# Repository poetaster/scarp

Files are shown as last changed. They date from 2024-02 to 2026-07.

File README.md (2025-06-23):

# scarp
The scarp project, named like it's brethren, rampart and keep (aka. moat) is an experimental, open hardware design. 

PCB

It can include a 4pin I2C display. Or a three pin I2S DAC. All the pins on the pico are exposed and you can add headers to use them.

The board uses all GPIO. 8 buttons, 8 leds, 2 pots and an encoder.

The firmware directory includes a number of types of firmware. You'll be able to do work with the bare pico sdk, circuitpython, or arduino. 

# firmwares
Include examples for
 *  NEW 05.2025 a port of Mutable instruments braids to scarp. Requires the STMLIB and BRAIDS libraries from https://github.com/poetaster/arduinoMI/
 *  Mozzi library based c++. 
 * Arduino PWM pikobeats variant. 
 * pikocore  The scarp branch here: https://github.com/poetaster/pikocore/tree/scarp allows you to play the pikocore firmware, with some tweaks to adapt to this hardware layout.
 * circuitpython - There is also an elaborate circuitpython audio example based on todbots https://github.com/todbot/picostepseq but including audio output ;)

I sell my tonetoys synths at https://poetaster.org or on etsy at https://tonetoys.etsy.com, or Tindie :)


 
I've had a bunch of fun with:

A Drum sequencer for the Pikocore, https://github.com/poetaster/PikoBeats, derived from https://github.com/rheslip/PikoBeats .

This project was inspired by Teenage Engineering, pikocore designed by Zack Scholl https://infinitedigits.co/wares/pikocore/, the todbot circuit python audio stuff and his layouts for a simple sequencer. Please visit Zack's site to buy a Pikocore, a kit, or a PCB - its a really fun little sample glitcher.

THIS BOARD is in production and the first version, with only pwm output works really well!.

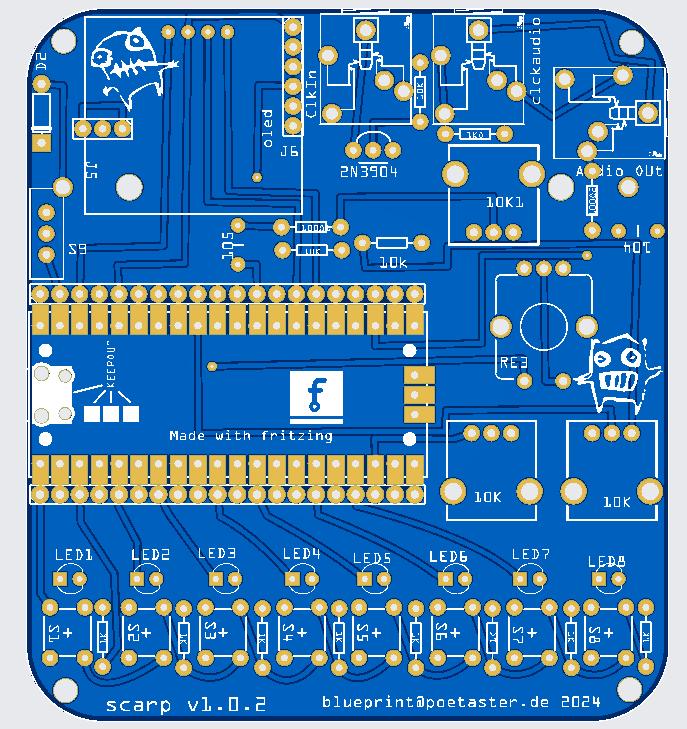
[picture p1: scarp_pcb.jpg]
PCB


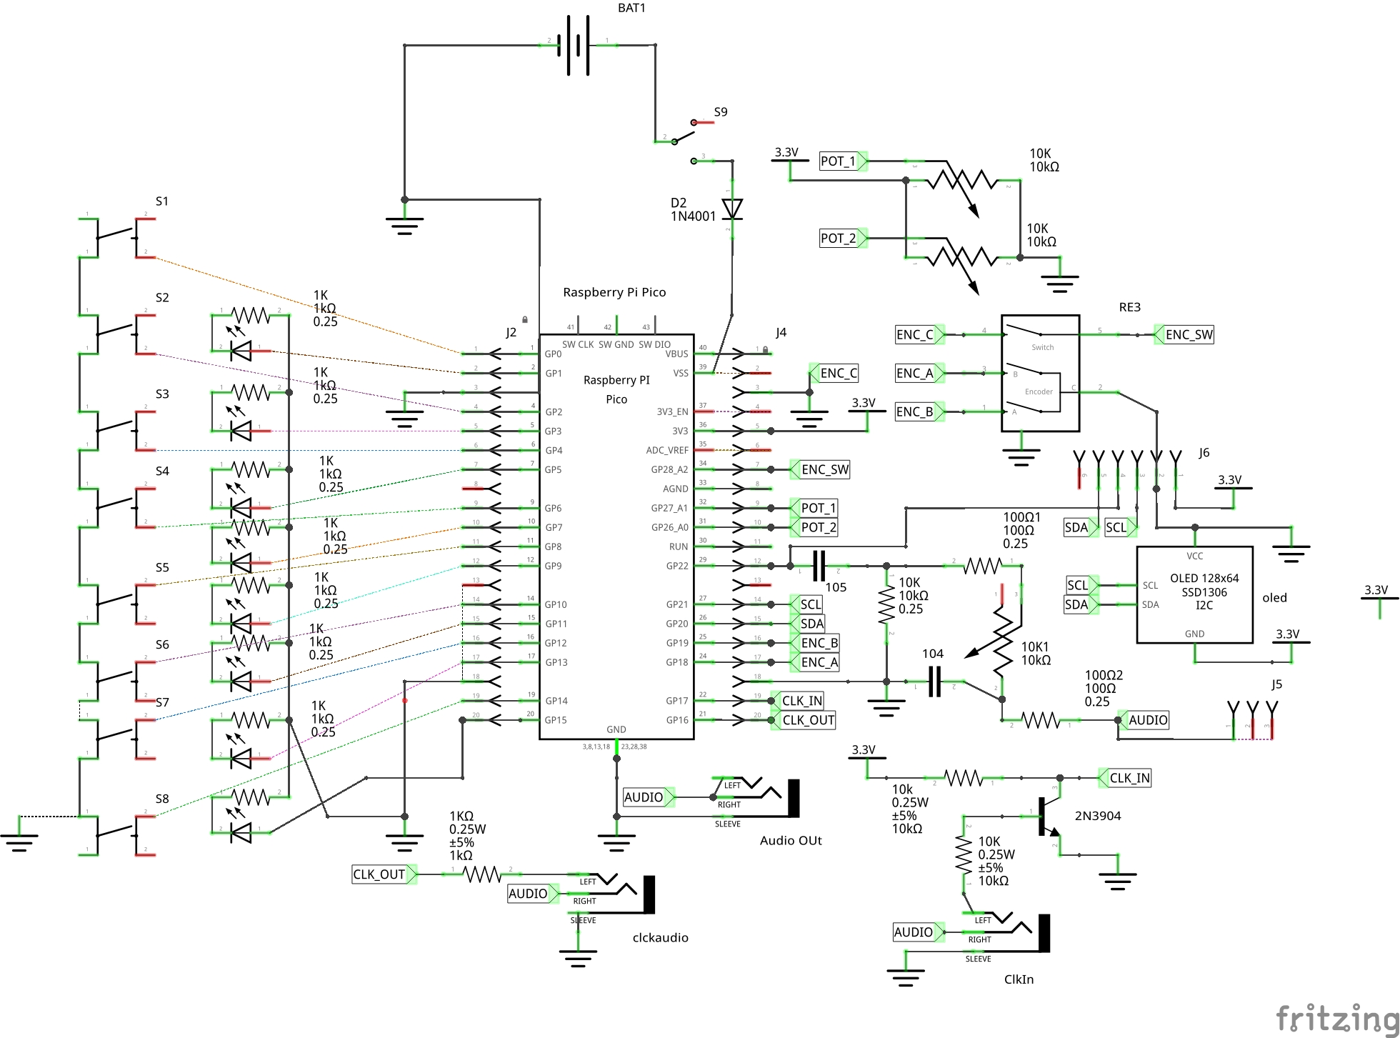
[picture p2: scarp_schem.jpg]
Schematic


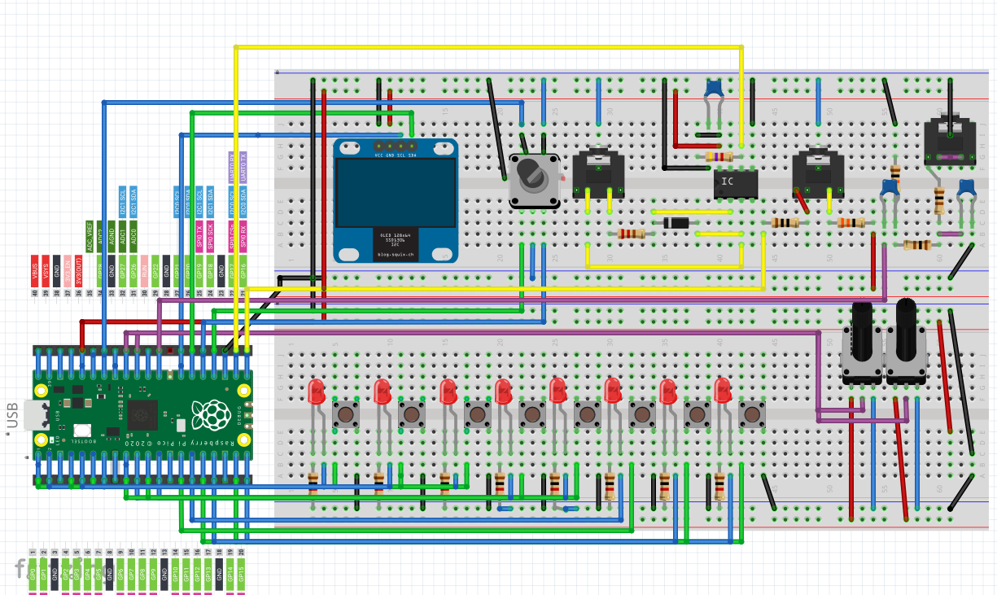
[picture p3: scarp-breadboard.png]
Breadboard


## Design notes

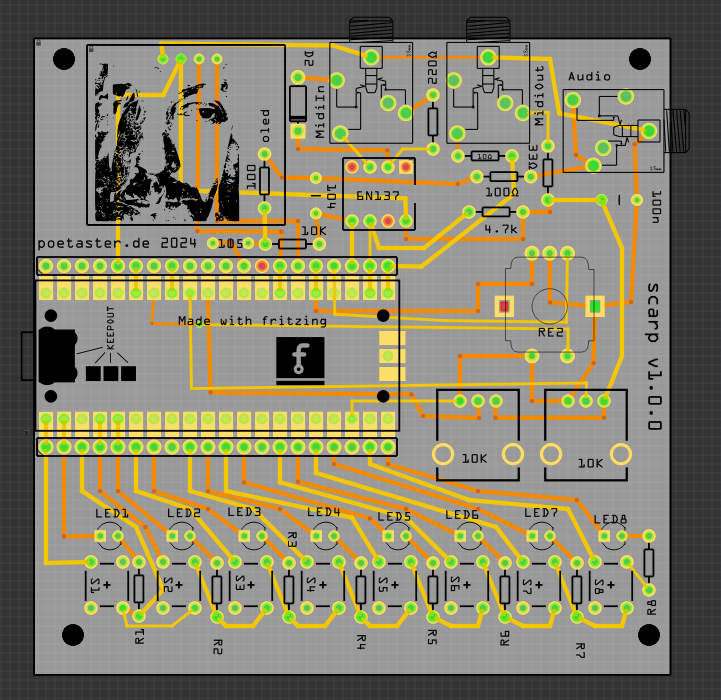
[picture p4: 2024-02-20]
scarp-pcb.png

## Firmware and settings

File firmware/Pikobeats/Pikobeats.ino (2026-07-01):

/* Copyright 2023 Rich Heslip, 2024-2025 Mark Washeim

  Author: Rich Heslip (ORIGINAL AUTHOR)
  Author: Mark Washeim <blueprint@poetaster.de>

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
  See http://creativecommons.org/licenses/MIT/ for more information.

  -----------------------------------------------------------------------------


  // sample player inspired by Jan Ostman's ESP8266 drum machine http://janostman.wordpress.com

  samples for beatbox from:
  giddster ( https://freesound.org/people/giddster/ )
  AlienXXX ( https://freesound.org/people/AlienXXX/

  The euclid code originates at:
  https://github.com/bastl-instruments/one-chip-modules/blob/master/EUCLID/EUCLID.ino

*/

#include <Arduino.h>
#include "stdio.h"
#include "pico/stdlib.h"
#include "hardware/gpio.h"
#include "hardware/sync.h"
#include "hardware/structs/ioqspi.h"
#include "hardware/structs/sio.h"

#include <EEPROM.h>
#include <PWMAudio.h>
#include <Wire.h>
#include <RotaryEncoder.h>

#include "io.h"
#include "euclid.h"

#include <math.h>     // tanhf for the output soft-clip
//#include "filter.h"

bool debug = false;
uint8_t device_initialized = 0;

// display setup works with adafruit SSD1306 or SH1106G
const int dw = 128;
const int dh = 64;
const int oled_sda_pin = 20;
const int oled_scl_pin = 21;
const int oled_i2c_addr = 0x3C;
#define OLED_RESET     -1 // Reset pin # (or -1 if sharing Arduino reset pin)
#define SCREEN_ADDRESS 0x3C ///< See datasheet for Address; 0x3D for 128x64, 0x3C for 128x32

//#include <Adafruit_SSD1306.h>
//Adafruit_SSD1306 display(dw, dh, &Wire, OLED_RESET);
//#define SCREEN_ADDRESS 0x3D ///< See datasheet for Address; 0x3D for 128x64, 0x3C for 128x32

#include <Adafruit_SH110X.h>
Adafruit_SH1106G display = Adafruit_SH1106G(128, 64, &Wire);
#define WHITE SH110X_WHITE
#include "font.h"
#include "helvnCB6pt7b.h"
#define myfont Org_01 //helvnCB6pt7b // Org_01 looks better but is small.
#define bigfont helvnCB6pt7b

#define DISPLAY_TIME 2000 // time in ms to display numbers on LEDS
int32_t display_timer;


// rotate trigger pattern
uint16_t rightRotate(int shift, uint16_t value, uint8_t pattern_length) {
  uint16_t mask = ((1 << pattern_length) - 1);
  value &= mask;
  return ((value >> shift) | (value << (pattern_length - shift))) & mask;
}

// clock timer we use for clk input and encoder input bpm setting
#define TIMER_INTERRUPT_DEBUG         0
#define _TIMERINTERRUPT_LOGLEVEL_     4
#include "RPi_Pico_TimerInterrupt.h"
#define TIMER0_INTERVAL_MS       1
#define DEBOUNCING_INTERVAL_MS   4// 80
#define LOCAL_DEBUG              1

// Init RPI_PICO_Timer, can use any from 0-15 pseudo-hardware timers
RPI_PICO_Timer ITimer0(0);

volatile unsigned long rotationTime = 0;
volatile float RPM       = 0.00;
float avgRPM    = 0.00;
volatile int debounceCounter;

int current_track = 0; // track we are working on

// input clk tracking
volatile int clk_state_last; // track the CLOCKIN pin state.
int clk_state = 0;
int clk_hits = 0;
uint32_t clk_sync_ms = 0;
bool sync = false; // used to detect if we have input sync
volatile int clk_display;
uint32_t clk_sync_last;

bool TimerHandler0(struct repeating_timer *t)
{
  (void) t;
  
  bool clockstate = digitalRead(CLOCKIN) ;
  
  if ( clockstate && clk_state_last != clockstate && (debounceCounter >= DEBOUNCING_INTERVAL_MS ) ) {
    //min time between pulses has passed
    // calculate bpm
    RPM = (float) ( 60000.0f / ( rotationTime * TIMER0_INTERVAL_MS ) / 2.0f );
    clk_display = RPM;
    // these are for the sequencer
    sync = true;
    rotationTime = 0;
    debounceCounter = 0;
  } else {
    debounceCounter++;
  }

  if (rotationTime >= 1000) {
    // If idle, set RPM to 0, don't increase rotationTime
    sync = false ;// flag for seq.h
    RPM = 0;
    rotationTime = 0;
  } else {
    rotationTime++;
  }

  clk_state_last = clockstate;
  return true;

}

// begin hardware definitions
const int key_pins[] = { 0, 2, 4, 6, 8, 10, 12, 14 };
const int led_pins[] = { 1, 3, 5, 7, 9, 11, 13, 15 };

// on the long ec11 these are swapped A 19, B 18
const int encoderA_pin = 18;
const int encoderB_pin = 19;
const int encoderSW_pin = 28;

// Encoder direction. 1 = normal, -1 = inverted. The CI builds both variants by
// passing -DCHAMBORD_ENC_DIR=... ; to change it locally edit the default below.
#ifndef ENC_DIR
#define ENC_DIR 1
#endif
const int ENCODER_DIR = ENC_DIR;


// encoder
RotaryEncoder encoder(encoderB_pin, encoderA_pin, RotaryEncoder::LatchMode::FOUR3);

void checkEncoderPosition() {
  encoder.tick();   // call tick() to check the state.
}

// variables for UI state management
int encoder_pos_last = 0;
int encoder_delta = 0;
uint32_t encoder_push_millis;
uint32_t step_push_millis;
uint8_t selected_preset = 0;
uint8_t selected_slot   = 0; // saving to

// the display is offset + 1
uint8_t display_preset = 0;
uint8_t display_slot = 0;

uint8_t loadSave = 0;
bool loading = false;

// currently not used
int step_push = -1;
bool step_edited = false;
char seq_info[11];  // 10 chars + nul FIXME

bool encoder_held = false;

// pots & buttons settings and functions
#include "pots.h"


enum {
  MODE_PLAY = 0,
  MODE_CONFIG,
  MODE_COUNT   // how many modes we got
};

int display_mode = MODE_PLAY;
uint8_t display_repeats = 0;
uint8_t display_fills = 0;
uint8_t display_rand = 0;
uint8_t display_samp = 0;
uint8_t display_vol = 175;
uint8_t display_pitch = 128;
String display_pat;

int modulation_timer = 0;
int rotation_timer = 0;
uint8_t last_mod_chan = 0;
uint8_t last_rot_chan = 0;

// from pikocore filter NOT used currently
/*
  uint8_t filter_fc = LPF_MAX + 10;
  uint8_t hpf_fc = 0;
  uint8_t filter_q = 0;
*/

//#define MONITOR_CPU  // define to monitor Core 2 CPU usage on pin CPU_USE

// setup audio hardware
#define SAMPLERATE 44100 // VCC-GND 16mb flash boards won't overclock fast enough for 44khz ?
PWMAudio DAC(PWMOUT);  // 16 bit PWM audio

/* we have 8 voices that can play any sample when triggered
  this structure holds the settings for each voice
  each voice has 4 samples assigned to it for a total of 32
  we use a header per sample set
  we can have an arbitrary number of samples but you will run out of memory at some point

  sound sample files are 22khz 16 bit signed PCM format - see the sample include files for examples
  you can change the sample rate to whatever you want but most testing was done at 22khz. 44khz probably works but not much testing was done
  use the wave2header22khz.exe utility to automagically batch convert all the .wav files in a directory into the required header files
  put your 22khz or 44khz PCM wav files in a sample subdirectory with a copy of the utility, run the utility and it will generate all the required header files
  wave2header creates a header file containing the signed PCM values for each sample - note that it may change the name of the file if required to make it "c friendly"
  wave2header also creates sampledefs.h which is an array of structures containing information about each sample file
  the samples are arranged in alphabetical order to facilitate grouping samples by name - you can manually edit this file to change the order of the samples as needed
  sampledefs.h contains other information not used by this program e.g. the name of the sample file - I wrote it for another project
   wave2header also creates "samples.h" which #includes all the generated header files
*/

#define KIT_HIPHOP

#if   defined(KIT_80S)
  #include "80s.h"
#elif defined(KIT_ANGULARJ)
  #include "angularj.h"
#elif defined(KIT_MIX)
  #include "mixp.h"
#elif defined(KIT_TEKKE)
  #include "tekke.h"
#elif defined(KIT_HIPHOP)
  #include "hiphop.h"
#else
  #include "trippy.h"
#endif

// the beatboxes need to be redone 02.12.2025
//#include "beatbox.h"
//#include "bbox.h"

#define NUM_SAMPLES (sizeof(sample)/sizeof(sample_t))


// include here to avoid forward references - I'm lazy :)
#include "seq.h"
#include "eeprom.h"

bool saveStatus = false;
#include "display.h"

// ---------------------------------------------------------------------------
// Audio mixing: precomputed per-voice gain + attack ramp (anti-click)
// Derived from wgd chambord
// ---------------------------------------------------------------------------

#define RAMP_LEN 48                 // ~1.1ms attack at 44.1kHz to kill retrigger clicks
int32_t  voice_gain[NTRACKS];       // Q15 gain (level/1000) precomputed so the mix loop has no divide
uint16_t voice_ramp[NTRACKS];       // attack ramp counter per track, counts up to RAMP_LEN

// set a track level (0-1000) and recompute its Q15 mix gain
inline void setLevel(int track, int level) {
  if (level < 0) level = 0;
  if (level > 1000) level = 1000;
  voice[track].level = level;
  voice_gain[track] = ((int32_t)level * 32768) / 1000;
}

bool starting = false;

// main core setup
void setup() {
  // set clock speed as in picokore
  //set_sys_clock_khz(264000, true); don't do this :)

  Serial.begin(115200);

  if (debug) {
    Serial.print(F("\nStarting RPM_Measure on ")); Serial.println(BOARD_NAME);
    Serial.println(RPI_PICO_TIMER_INTERRUPT_VERSION);
    Serial.print(F("CPU Frequency = ")); Serial.print(F_CPU / 1000000); Serial.println(F(" MHz"));
  }
  // Interval in microsecs
  if (ITimer0.attachInterruptInterval(TIMER0_INTERVAL_MS * 1000, TimerHandler0))
  {
    Serial.print(F("Starting  ITimer0 OK, millis() = ")); Serial.println(millis());
  }  else {
    Serial.println(F("Can't set ITimer0. Select another freq. or timer"));
  }
  //Serial.flush();

  // Additions
  // ENCODER
  pinMode(encoderA_pin, INPUT_PULLUP);
  pinMode(encoderB_pin, INPUT_PULLUP);
  attachInterrupt(digitalPinToInterrupt(encoderA_pin), checkEncoderPosition, CHANGE);
  attachInterrupt(digitalPinToInterrupt(encoderB_pin), checkEncoderPosition, CHANGE);

  // DISPLAY need to tell Wire which pins for i2c
  Wire.setSDA(oled_sda_pin);
  Wire.setSCL(oled_scl_pin);
  Wire.begin();

  // SSD1306 --
  //if (!display.begin(SSD1306_SWITCHCAPVCC, oled_i2c_addr)) {
  if (!display.begin( oled_i2c_addr)) {
    Serial.println(F("SSD1306 allocation failed"));
    for (;;) ;  // Don't proceed, loop forever
  }

  displaySplash();
  //displayConfig();

  // end Additions

#ifdef MONITOR_CPU
  pinMode(CPU_USE, OUTPUT); // for monitoring CPU usage
#endif

  pinMode(BUTTON0, INPUT_PULLUP);
  pinMode(BUTTON1, INPUT_PULLUP);
  pinMode(BUTTON2, INPUT_PULLUP);
  pinMode(BUTTON3, INPUT_PULLUP);
  pinMode(BUTTON4, INPUT_PULLUP);
  pinMode(BUTTON5, INPUT_PULLUP);
  pinMode(BUTTON6, INPUT_PULLUP);
  pinMode(BUTTON7, INPUT_PULLUP);
  pinMode(SHIFTBUTTON, INPUT_PULLUP);

  pinMode(AIN0, INPUT);
  pinMode(AIN1, INPUT);

  pinMode(LED0, OUTPUT);
  pinMode(LED1, OUTPUT);
  pinMode(LED2, OUTPUT);
  pinMode(LED3, OUTPUT);
  pinMode(LED4, OUTPUT);
  pinMode(LED5, OUTPUT);
  pinMode(LED6, OUTPUT);
  pinMode(LED7, OUTPUT);

  pinMode(CLOCKOUT, OUTPUT);
  pinMode(CLOCKIN, INPUT_PULLUP);

  pinMode(23, OUTPUT); // thi is to switch to PWM for power to avoid ripple noise
  digitalWrite(23, HIGH);

  display_value(NUM_SAMPLES); // show number of samples on the display

  // init per-voice mix gains and ramps, then restore saved settings from flash
  for (int t = 0; t < NTRACKS; ++t) {
    setLevel(t, voice[t].level);
    voice_ramp[t] = RAMP_LEN;   // not ramping until first trigger
  }

  // try to retrieve saved preset if not, init slots
  EEPROM.begin(2048); // the 8 slots we save now are only 384 bytes, but it'll probably grow
  delay(50);

  starting = true;



  // we read the first byte to try to get a preset, stored 0-7
  if (starting) {
    loading = true;
    loadInit();
    if (device_initialized == 7 ) {

      loadLastPreset(); // sets selected_preset from base eeprom save point
      loadMemorySlots();
      if (selected_preset > -1 && selected_preset < 8) {

        loadFromMemorySlot(selected_preset);

      } else {
        loadFromMemorySlot(0);
      }

    } else {
      // first use of device, so prep it.
      initializeEEPROM(); // first run, get settings into all 8 slots
      currentConfig = defaultSlots[0]; // current config is default 0
      bpm = currentConfig.tempo;
      internalClock = currentConfig.internalClock;
      selected_preset = 0;
      saveCurrentPreset(selected_preset); // save to eeprom

      updateRythm(); // update the sequencers

      writeInit(); // set flag so we don't repeat
    }

    starting = false;
    loading = false;
  }

  // init per-voice mix gains and ramps, then restore saved settings from flash
  for (int t = 0; t < NTRACKS; ++t) {
    setLevel(t, voice[t].level);
    voice_ramp[t] = RAMP_LEN;   // not ramping until first trigger
  }


  // now start the dac
  // set up Pico PWM audio output
  DAC.setBuffers(4, 128); // DMA buffers
  DAC.begin(SAMPLERATE);
  delay(100);
  modulation_timer = millis();
  rotation_timer = millis();
}



// main core handles UI

void loop() {


  bool anybuttonpressed;
  // timer
  uint32_t now = millis();



  // UI handlers
  // first encoder
  encoder.tick();
  int encoder_pos = encoder.getPosition();
  if ( (encoder_pos != encoder_pos_last )) {
    encoder_delta = (encoder_pos - encoder_pos_last) * ENCODER_DIR;
  }


  // set play mode 0 play 1 edit patterns, 3 FX?
  if (encoder_push_millis > 0 ) {

    // first mode change on encoder button push, short
    if ((now - encoder_push_millis) < 100 && ! encoder_delta ) {
      if ( !encoder_held ) {
        encoder_held = true;
        display_mode = display_mode + 1;
        if ( display_mode > 3) { // switched back to play mode
          display_mode = 0;
          //configure_sequencer();
        }
      }
    } else if ( (now - encoder_push_millis) > 100 && ! encoder_delta && display_mode == 3 ) {
      // or change  between load and save preset
      //loadSave = !loadSave ; // toggle between load and save
    }

    if (step_push_millis > 0) { // we're pushing a step key too
      if (encoder_push_millis < step_push_millis) {  // and encoder was pushed first
        //strcpy(seq_info, "saveseq");
      }
    }
  }

  anybuttonpressed = false;

  for (int i = 0; i <= 8; ++i) { // scan all the buttons
    if (button[i]) {

      saveStatus = false; // for display when saving
      anybuttonpressed = true;

      // a track button is pressed
      current_track = i; // keypress selects track we are working on

      // use encoder delta with selected button to set sample for track
      if ( (encoder_pos != encoder_pos_last ) && ! button[8] && display_mode == 0) {
        voice[i].isPlaying = false;
        // here we rotate at offset since we're now arranging sample sets in groups of 4
        // currently only really works with 'mix.h'
        int result ;
        if (encoder_delta > 0) {
          result = voice[current_track].sample + 8 ;
        } else {
          result = voice[current_track].sample - 8 ;
        }
        if (result >= 0 && result <= NUM_SAMPLES - 1) {
          voice[current_track].sample = result;
          voice_ramp[current_track] = 0; // re-attack to soften the swap if it's ringing
          currentConfig.sample[i] = result; // save config 0 - 31

        }
      }

      // use encoder button with selected button to set the offset
      if ( (encoder_pos != encoder_pos_last ) && display_mode == 1 ) {
        int repeats = seq[current_track].repeats;
        repeats = constrain( (repeats + encoder_delta), 0, 5);
        seq[i].repeats = repeats;

        // repeats are actually now OFFSET. the repeats mechanism with rotate
        // was disturbing

        display_repeats = repeats;
        seq[i].trigger->rotate(repeats);
        currentConfig.offset[i] = repeats;

        // if offset is 0, reset
        if (repeats == 0 && currentConfig.randy[i] == 0) {
          seq[i].trigger->generateSequence(seq[i].fills, 16);
        } else if (repeats == 0 && currentConfig.randy[i] == 1) {
          seq[i].trigger->generateRandomSequence(seq[i].fills, 16);
        }

      }
      // either restrieve or save preset
      if ( display_mode == 3 &&  ! button[8] ) {
        if (loadSave == 0 && ! loading ) {
          loading = true;
          currentConfig.tempo = bpm;
          updateMemorySlot(selected_preset); // update the memory slot before switching
          selected_preset = current_track;
          saveToEEPROM(current_track);
          saveStatus = true;
          loading = false;
          //saveStatus = false;


        } else if (loadSave == 1 && ! loading && selected_preset != current_track) {
          loading = true; // make sure audio is off
          currentConfig.tempo = bpm;
          updateMemorySlot(selected_preset); // update the memory slot before switching
          selected_preset = current_track; // set selected preset
          loadFromMemorySlot(current_track); // load it from memory
          loading = false;
        }

      }

      // change pitch on pot 0
      if (!potlock[0] && ( display_mode == 0 || display_mode == 2) ) { // change sample if pot has moved enough
        uint16_t pitch = (uint16_t)(map(potvalue[0], POT_MIN, POT_MAX, 2048, 8160));
        // divisible by 2 and it won't click
        if (pitch % 2 == 0) {
          voice[current_track].sampleincrement = pitch;  // change sample pitch if pot has moved enough
          display_pitch = constrain( (pitch >> 5), 1, 255) ; // show 8 bits, which we also store
          currentConfig.pitch[i] = display_pitch; // update config for this channel
        }
      }

      // change sample volume level if pot has moved enough
      if (!potlock[1] && display_mode == 0) {
        int16_t level = (int16_t)(map(potvalue[1], POT_MIN, POT_MAX, 0, 1023));
        voice[current_track].level = level;
        setLevel(current_track, voice[current_track].level);
        display_vol = constrain( ( level >> 2 ), 1, 255); // show 8 bits which we store
        currentConfig.volume[i] = display_vol;
      }
      if (!potlock[0] && display_mode == 1 ) {
        // set track euclidean triggers, random, if either pot has moved enough
        //filter_fc = potvalue[0] * (LPF_MAX + 10) / 4096;
        seq[i].fills = map(potvalue[0], POT_MIN, POT_MAX, 0, 16);
        seq[i].trigger->generateRandomSequence(seq[i].fills, 16);
        currentConfig.randy[i] = 1;
        currentConfig.fills[i] = seq[i].fills;

      }

      // set track euclidean triggers if either pot has moved enough
      if (!potlock[1] && ! button[8] && display_mode == 1) {
        seq[i].fills = map(potvalue[1], POT_MIN, POT_MAX, 0, 16);
        seq[i].trigger->generateSequence(seq[i].fills, 16);
        seq[i].trigger->resetSequence(); // set to 0
        currentConfig.randy[i] = 0;
        currentConfig.fills[i] = seq[i].fills;

      }
      //trig/retrig play
      if ( display_mode == 2 && i < 8 && voice[current_track].isPlaying == false) {
        voice[current_track].sampleindex = 0; // trigger sample for this track
        voice[current_track].isPlaying = true;

      }
      /*
        if (!potlock[2]) {
        seq[i].trigger->setRepeats(map(potvalue[2], POT_MIN, POT_MAX, 0, 32));
        //seq[i].trigger= rightRotate(map(potvalue[2],POT_MIN,POT_MAX,0,MAX_SEQ_STEPS-1),seq[i].trigger,16); // rotate trigger pattern
        }
      */


    }
    // update display values on and update config object with changes
    // do not update values on load save screen
    if (current_track > -1 && current_track < 8 && display_mode != 3) {
      display_pat = String(seq[current_track].trigger->textSequence);
      display_pitch = currentConfig.pitch[current_track] ;
      display_vol = currentConfig.volume[current_track] ;
      display_repeats = seq[current_track].repeats;
      display_fills = seq[current_track].fills;
      display_rand = currentConfig.randy[current_track];
      display_samp = voice[current_track].sample;
      currentConfig.tempo = bpm;
      updateMemorySlot(selected_preset); // update the memory slot before switching
    }
  }


  // now, after buttons check if only encoder moved and no buttons
  if (! anybuttonpressed && encoder_delta && display_mode != 3) {
    bpm = bpm + encoder_delta;
    currentConfig.tempo = bpm;
    displayUpdate();
    display_value(bpm - 50);
  } else if (! anybuttonpressed && encoder_delta && display_mode == 3) {
    // in load save mode, switch between load and save
    if (encoder_delta > 0) {
      loadSave = 0 ;
    } else {
      loadSave = 1;
    }
  }

  /// only set new pos last after buttons have had a chance to use the delta
  encoder_pos_last = encoder_pos;
  encoder_delta = 0;  // we've used it

  // start tracking time encoder button held
  if (button[8]) {
    encoder_push_millis = now;
  } else {
    encoder_push_millis = 0;
    encoder_held = false;
  }

  // lock pot settings when no keys are pressed so it requires more movement to change value
  // this is so when we change tracks we don't immediately change the settings on the new track
  if (!anybuttonpressed) lockpots();

  scanbuttons();

  // reading A/D seems to cause noise in the audio so don't do it too often
  if ((now - pot_timer) > POT_SAMPLE_TIME) {
    readpot(0);
    readpot(1);
    pot_timer = now;
  }

  // do random modulation on volume
  // this is not so nice although it does work
  // it should be a gradual change over time,
  // not a hard cut
/*
  if ( (now - modulation_timer ) > 50 ) {

    // set a new channel
    int chan = constrain ( (random(8) - 1) , 0, 7) ;

    // don't do this if the channels are playing
    if (  voice[chan].isPlaying == false && voice[last_mod_chan].isPlaying == false ) {

      // restore the configured volume of last modified
      voice[last_mod_chan].level = ( currentConfig.volume[last_mod_chan] << 2);

      // set a new level based on previous
      int level = constrain( random(voice[chan].level) , 300, voice[chan].level);
      voice[chan].level = level;
      last_mod_chan = chan;

    }

    modulation_timer = now;

  }
  */
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

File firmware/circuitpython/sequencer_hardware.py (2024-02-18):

# sequencer_hardware.py -- picostepseq hardware specific setup
# 10 Aug 2022 - @todbot / Tod Kurt
# Part of picostepseq : https://github.com/todbot/picostepseq/


import board
import busio
import pwmio
import rotaryio
import keypad
import displayio
import digitalio
import adafruit_displayio_ssd1306

dw,dh = 128,64

# we flipped 
key_pins = (board.GP0, board.GP2, board.GP4, board.GP6,
            board.GP8, board.GP10, board.GP12, board.GP14)

led_pins = (board.GP1, board.GP3, board.GP5, board.GP7,
            board.GP9, board.GP11, board.GP13, board.GP15)
# flip A & B
encoderB_pin, encoderA_pin, encoderSW_pin = board.GP18, board.GP19, board.GP28 # was 22

oled_sda_pin, oled_scl_pin = board.GP20, board.GP21

midi_tx_pin, midi_rx_pin = board.GP16, board.GP17

#def make_led(p): po = pwmio.PWMOut(p, frequency=25000, duty_cycle=0); return po
def make_led(p): 
    po = digitalio.DigitalInOut(p); 
    po.direction = digitalio.Direction.OUTPUT
    po.value = True
    return po

class Hardware():
    def __init__(self):
        # KEYS
        self.keys = keypad.Keys(key_pins, value_when_pressed=False, pull=True)
        self.step_to_key_pos = (0,1,2,3,4,5,6,7)

        # LEDS
        # create the objects handling those pin functions
        self.leds = [ make_led(p) for p in led_pins ]
        #self.leds_fade_amount = 30

        # KNOB
        self.encoder = rotaryio.IncrementalEncoder(encoderA_pin, encoderB_pin)
        self.encoder_switch = keypad.Keys((encoderSW_pin,), value_when_pressed=False, pull=True)

        # DISPLAY
        oled_i2c = busio.I2C( scl=oled_scl_pin, sda=oled_sda_pin, frequency=400_000 )
        display_bus = displayio.I2CDisplay(oled_i2c, device_address=0x3C)  # or 0x3D depending on display
        self.display = adafruit_displayio_ssd1306.SSD1306(display_bus, width=dw, height=dh)

        # # uart midi setup
        #midi_timeout = 0.01
        self.midi_uart = busio.UART(tx=midi_tx_pin, rx=midi_rx_pin, baudrate=31250) # timeout=midi_timeout)

    # set LED brightness to value from 0-255
    def led_set(self,i,v):
        self.leds[i].value = v
        #self.leds[i].duty_cycle = v * 256  # duty_cycle 0-65535

    # get LED brightness to value 0-255
    def led_get(self,i):
        return self.leds[i].duty_cycle // 256

    # refresh all LEDs (if meaningful)
    def leds_show(self):
        pass

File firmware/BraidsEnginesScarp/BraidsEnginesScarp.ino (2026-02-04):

/*
  (c) 2025 blueprint@poetaster.de GPLv3

   Based on  mi_Ugens, Copyright (c) 2020 Volker Böhm. All rights reserved. GPLv3
   https://vboehm.net

   Mutable Instruments sources, including the stmlib, tides, plaits elements and braids libs are
   MIT License
   Copyright (c)  2020 (emilie.o.gillet@gmail.com)
*/

bool debugging = true;

#include <Arduino.h>
#include "stdio.h"
#include "pico/stdlib.h"
#include "hardware/gpio.h"
#include "hardware/sync.h"
#include <hardware/pwm.h>

#include <PWMAudio.h>
#define SAMPLERATE 48000
#define PWMOUT 22
PWMAudio DAC(PWMOUT);  // 16 bit PWM audio

#include "Midier.h"

// button inputs
#define BUTTON0  0 // key1 input on schematic
#define BUTTON1  2
#define BUTTON2 4
#define BUTTON3 6
#define BUTTON4 8
#define BUTTON5 10
#define BUTTON6 12
#define BUTTON7 14  // for the Pico board
#define SHIFTBUTTON 28 // was 24 USR button on VCC-GND boards

#define LED0 1 // LED1 output on schematic
#define LED1 3
#define LED2 5
#define LED3 7
#define LED4 9
#define LED5 11
#define LED6 13
#define LED7 15
#define LED 15 // shows if MIDI is being recieved
// analog freq pins

#include <MIDI.h>
#include <Wire.h>


//MIDI_CREATE_DEFAULT_INSTANCE();

// braids dsp

//const uint16_t decimation_factors[] = { 1, 2, 3, 4, 6, 12, 24 };
const uint16_t bit_reduction_masks[] = {
  0xffff,
  0xfff0,
  0xff00,
  0xf800,
  0xf000,
  0xe000,
  0xc000
};

#define     MI_SAMPLERATE      96000.f
#define     BLOCK_SIZE          32      // --> macro_oscillator.h !
#define     SAMP_SCALE          (float)(1.0 / 32756.0)


#include <STMLIB.h>
#include <BRAIDS.h>
#include "ADSR.h"
// create ADSR env
ADSR *env = new ADSR();

typedef struct
{
  braids::MacroOscillator *osc;

  float       samps[BLOCK_SIZE] ;
  int16_t     buffer[BLOCK_SIZE];
  uint8_t     sync_buffer[BLOCK_SIZE];

} PROCESS_CB_DATA ;

int16_t shared_buffer[BLOCK_SIZE];


bool envRelease = false;
long envTimer = 0;

//float a0 = (440.0 / 8.0) / kSampleRate; //48000.00;
const size_t   kBlockSize = BLOCK_SIZE;


struct Unit {
  braids::Quantizer   *quantizer;
  braids::SignatureWaveshaper *ws;
  bool            last_trig;
  // resampler
  //SRC_STATE       *src_state;
  PROCESS_CB_DATA pd;
  float           *samples;
  float           ratio;
};

static long src_input_callback(void *cb_data, float **audio);

struct Unit voices[1];

// Plaits modulation vars
float morph_in = 0.7f; // IN(4);
float trigger_in; //IN(5);
float level_in = 0.0f; //IN(6);
float harm_in = 0.1f;
float timbre_in = 0.1f;
int engine_in;

float fm_mod = 0.0f ; //IN(7);
float timb_mod = 0.0f; //IN(8);
float morph_mod = 0.0f; //IN(9);
float decay_in = 0.5f; // IN(10);
float lpg_in = 0.1f ;// IN(11);
int pitch_in = 60;


// Braids vars
//    float   voct_in = IN0(0);
//    float   timbre_in = IN0(1);
//    float   color_in = IN0(2);
//    float   model_in = IN0(3);
//    float   *trig_in = IN(4);

// clock timer  stuff

#define TIMER_INTERRUPT_DEBUG         0
#define _TIMERINTERRUPT_LOGLEVEL_     4

// Can be included as many times as necessary, without `Multiple Definitions` Linker Error
#include "RPi_Pico_TimerInterrupt.h"

//unsigned int SWPin = CLOCKIN;

#define TIMER0_INTERVAL_MS 20.833333333333   // \20.833333333333running at 48Khz
#define DEBOUNCING_INTERVAL_MS   2// 80
#define LOCAL_DEBUG              0

volatile int counter = 0;

// Init RPI_PICO_Timer, can use any from 0-15 pseudo-hardware timers
RPI_PICO_Timer ITimer0(0);

bool TimerHandler0(struct repeating_timer *t) {
  (void) t;
  bool sync = true;
  if ( DAC.availableForWrite() ) {
    for (size_t i = 0; i < BLOCK_SIZE; i++) {
      //DAC.write( voices[0].pd.buffer[i], sync);
      DAC.write( shared_buffer[i], sync); //try using envelope
    }
    counter =  1;
  }
  return true;
}

// GPIO, pots
const int INTS_PIN = 26; // set the analog input for fm_intensity
const int RATE_PIN = 2; // set the analog input for mod rate
const int MODR_PIN = 27; // set the analog input for mod ratio

// encoder related
#include <RotaryEncoder.h>
const int encoderA_pin = 19;
const int encoderB_pin = 18;
const int encoderSW_pin = 28;

RotaryEncoder encoder(encoderB_pin, encoderA_pin, RotaryEncoder::LatchMode::FOUR3);

void checkEncoderPosition() {
  encoder.tick();   // call tick() to check the state.
}

// display related
const int oled_sda_pin = 20;
const int oled_scl_pin = 21;
const int oled_i2c_addr = 0x3C;
const int dw = 128;
const int dh = 64;

#define OLED_RESET     -1 // Reset pin # (or -1 if sharing Arduino reset pin)
#define SCREEN_ADDRESS 0x3C ///< See datasheet for Address; 0x3D for 128x64, 0x3C for 128x32
//Adafruit_SSD1306 display(dw, dh, &Wire, OLED_RESET);
//#include <Adafruit_SSD1306.h>

#include <Adafruit_SH110X.h>
Adafruit_SH1106G display = Adafruit_SH1106G(128, 64, &Wire);
#define WHITE SH110X_WHITE

#include "font.h"
#include "helvnCB6pt7b.h"
#define myfont helvnCB6pt7b // Org_01 looks better but is small.
#include "shapes.h" // char array of names of instruments.
#include "display.h"


// variables for UI state management
int encoder_pos_last = 0;
int encoder_delta = 0;
uint32_t encoder_push_millis;
uint32_t step_push_millis;
bool encoder_held = false;

// buttons & knobs defines/functions
#include "control.h"
// midi related functions
#include "midi.h"

// utility
double randomDouble(double minf, double maxf)
{
  return minf + random(1UL << 31) * (maxf - minf) / (1UL << 31);  // use 1ULL<<63 for max double values)
}



// audio related defines

//float freqs[12] = { 261.63f, 277.18f, 293.66f, 311.13f, 329.63f, 349.23f, 369.99f, 392.00f, 415.30f, 440.00f, 466.16f, 493.88f};
int freqs[12] = { 42, 44, 46, 48, 50, 52, 54, 56, 58, 60, 62, 64};
int carrier_freq;

int current_track;
int bpm = 120;

uint16_t noteA;
uint16_t noteM;
uint16_t attackIn = 8; // up to 384
uint16_t durationIn = 200; // up to 384
uint16_t modIn = 200; // up to 2800
uint16_t modC = 0;
int pressedB;
int RATE_value = 1 ; //was an adc in kevin's orig
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

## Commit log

2024-02-11 Init: initial project foo
    [scarp.fzz]
2024-02-11 Fix: missing v+ pots. clean up schematic
    [scarp.fzz]
2024-02-18 Fix: small board fixes. polarity and 2 misconnects
    [scarp.fzz]
2024-02-18 Add: circuitpython demo code using all ports and audio: based on https://github.com/todbot/picostepseq
2024-02-19 Add: add waveform morphing and filter to avoid boredom.
    [code.py]
2024-02-20 Fix: minor code. add proper pwm output to circuit
    [scarp.fzz]
2024-02-21 Fix: minor fixes. audio out
    [scarp.fzz]
2024-02-22 Fixes: all initial display, rotary and audio functions.
    [Pikobeats.ino, io.h]
2024-02-22 Fix: move some functions to rotary, some to pot 0.
    [Pikobeats.ino]
2024-02-24 Feature: move to modes. add repeats in on mode 1. mode 0 has pitch and volumen, mode1 filter, repeats, pattern
    [scarp.fzz]
2024-02-25 Fix: reworking for clock out for the pos and korgs.
    [scarp.fzz]
2024-03-03 Fix: add interrupt based timer for clk in. last tests with hardware
    [scarp.fzz]
2024-03-04 Add: produce distinct clk/midi variants
    [scarp.fzz, scarp_clock.fzz]
2024-03-10 Fix: timing fixes, layout of clock cleanup, slim down.
    [scarp_clock.fzz]
2024-03-20 [Release] another iteration for pcbs
    [scarp_clock.fzz]
2024-03-30 Fix: well we forgot a power switch
    [scarp_clock.fzz]
2024-03-31 Fix: for power switch. add a synth example with button control
    [scarp_clock.fzz]
2024-04-05 Fixes: add GPIO23 HIGH for noise reduction, modify placement of volume, FM synth mods
    [scarp_clock.fzz]
2024-04-05 Fixes: add GPIO23 HIGH and testing GP0 bug
    [MozziFM2.ino]
2024-04-07 Fix: dumb overflow error, add sda/scl alternates for I2S on mozzi
    [scarp_clock.fzz]
2024-04-11 Add: add running avg. not used currently
2024-04-12 Fix: resolve retrig init
    [Pikobeats.ino]
2024-04-27 Add: display vol, pitch, pattern. move to random pattern. minor layout on the fzz.
    [scarp_clock.fzz]
2024-05-04 Fix: correct rotate logic. add additional voices
    [scarp_clock.fzz]
2024-05-04 Fix: at 133mhz, non overclocking, use PPQN of 24 for PO sync. midi standard?
    [Pikobeats.ino, seq.h]
2024-05-12 Fix: minor layout and dumped debounce timer0 to 2ms. maybe just get rid of it
    [scarp_clock.fzz]
2024-05-24 Add: new pics
    [scarp_clock.fzz]
2024-05-24 Add: new samples
2024-05-26 Fix: corrected init of bpm value. add base 80s sample set
    [Pikobeats.ino]
2024-05-26 Fix: corrected offest for - bpm
    [Pikobeats.ino]
2024-05-27 Refactor: move sample assignmets to headers. move random pat to mode 1. move sample play to mode 2. add samples
2024-06-04 Readme: tonetoys sales note
    [scarp_clock.fzz]
2024-06-20 Fix: off by one on the euclide sequence. how embarassing!
    [Pikobeats.ino, euclid.cpp]
2025-02-02 Fixes and add header creation python
    [MozziFMsynth.ino, Pikobeats.ino]
2025-02-02 Add: filled pcb version
    [scarp_clock_filled.fzz]
2025-04-03 Add: schematic picture, gerber files
    [scarp_clock_filled_contour.gm1, scarp_clock_filled_copperBottom.gbl, scarp_clock_filled_copperTop.gtl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]
2025-04-17 Update: last schematic
2025-06-23 Fix: migrate last version of scarp braids
    [BraidsEnginesScarp.ino, Pikobeats.ino, display.h]
2025-06-24 Fix: make certain the sample is not playing before changing sample
    [Pikobeats.ino]
2025-11-12 Fix: correct repeats to offset. add mix set from chambord in 22khz
    [Pikobeats.ino, euclid.cpp]
2025-11-13 Add: eeprom settings save features, sample update
2025-11-13 Fix: attempt to stop playback on save / load. doesnt quite work
    [Pikobeats.ino]
2025-11-13 Fix: correct loading/saving of preset on start
    [Pikobeats.ino]
2025-11-14 Fix: eeprom on pi pico sucks.
    [Pikobeats.ino, display.h, eeprom.h]
2025-11-15 Fix: various init functions, display variables
    [Pikobeats.ino, display.h, eeprom.h]
2025-11-15 Fix: display pattern generation and display value sets
    [Pikobeats.ino, eeprom.h]
2025-11-15 Fix: move to internal memory for preset selection instead of loading
    [Pikobeats.ino, eeprom.h]
2025-11-15 Fix: do not disable dac.
    [Pikobeats.ino]
2025-11-15 Fix: save current preset only on leaving load save screen
    [Pikobeats.ino]
2025-11-15 Fix: move euclidean function call
    [euclid.cpp]
2025-11-15 Fix: save memory slot changes between loads
    [Pikobeats.ino, display.h, euclid.cpp]
2025-11-16 Fix: bpm / config object state fixes, display arrangement
    [Pikobeats.ino, display.h, eeprom.h]
2025-11-16 Fix: wavs and minor bpm glitch
    [Pikobeats.ino, display.h]
2025-11-16 Fix: once again, bpm on save.
    [Pikobeats.ino, eeprom.h]
2025-11-17 Add: missing drum files
    [Pikobeats.ino, eeprom.h]
2025-11-29 Fix: re-enable the clock input accidently disabled
    [scarp_clock.fzz]
2025-11-29 Fix: hmmm. move to 4 pulses which seems closer. makes no sense.
    [Pikobeats.ino]
2025-12-01 Fix: sync in was missing reset
    [Pikobeats.ino, seq.h]
2025-12-02 Fix: add debounce back, though it only goes till about 165bpm. Add notes
    [Pikobeats.ino, seq.h]
2026-06-30 [Fix] apply the rendering fixes from chambord
    [Pikobeats.ino, display.h]
2026-06-30 [Fix] missing encoder direction code
    [Pikobeats.ino]
2026-06-30 [Fix] we must update all tracks since changing bpm requires it
    [Pikobeats.ino]
2026-06-30 [Fix] move setlevel to correct routine
    [Pikobeats.ino]
2026-06-30 Correct trippy volumes Correct setLevel from preset loading Correct setLevel
    [Pikobeats.ino, eeprom.h]
2026-08-28 [Add] a new layout for silicon buttons
2026-08-28 [Add] new gerbers, copper fill
